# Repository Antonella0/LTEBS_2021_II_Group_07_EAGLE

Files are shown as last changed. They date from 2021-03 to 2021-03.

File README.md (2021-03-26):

# LTEBS_2021_II_Group_07_EAGLE
<h3> Group_07: Buquicchio Antonella, Di Liddo Mauro </h3>

<p> This folder contains all the files required for the first assignment. In particular you can find:
<u>
<li> The Library with the new components, TMUX1208 and TCA9546A
<li> The Schematic
<li> The Board
<li> The Design rules
<li> gitignore file </li>
</p>

<h3> Library: Group_07_Library.lbr </h3>
<p> In the library file are contained the two new components which are used in the schematic and in the board. For each device is present the symbol, the footprint and a
briefly description of the device itself. All the information are extracted from the datasheets of Texas Instruments:
<li> TMUX1208: the available package is QFN-16
<li> TCA9546A: the available package is TSSOP-16 </li>
</p>

<p> <b>Note_1</b>: In the TMUX1208, the association between pins of the symbol and pads of the footprint follows the QFN-16 one.</p>

<p> <b>Note_2</b>: The pads of the two components are realized with a rectangular shape without any roundness at the corners. </p>

</p>
<p> The graphical pins disposition of the TMUX1208 and TCA9546A is reorganized with respect to the one provided by the datasheets in order 
to allow an easier connection with the other components in the schematic.
</p>

</p>
<p> In addition to our library, we have used the SparkFun Library (https://github.com/sparkfun/SparkFun-Eagle-Libraries) and the CY8CKIT-059 Library 
(https://github.com/dado93/Cypress-Eagle). </p>

<h3>Schematic: Group_07.sch </h3>
<p> We have created the schematic starting from the given one and the list of components. It is arranged in one page.</p>

<h3>Board: Group_07.brd </h3>
<p> All the components are organized in the top layer. We have used traces width of 10 mils as requested with the exception of the TMUX1208 traces: indeed, the pads 
are very closed each others and, in order to respect the clearance requirements, we have decided to use 8 mils traces. 
</p>

<h3>Design Rules: Group_07.dru </h3>
<p>In order to decide the design rules, we have refered to the requirements of MDsrl (https://www.mdsrl.it/mddesignrules.html).
</p>

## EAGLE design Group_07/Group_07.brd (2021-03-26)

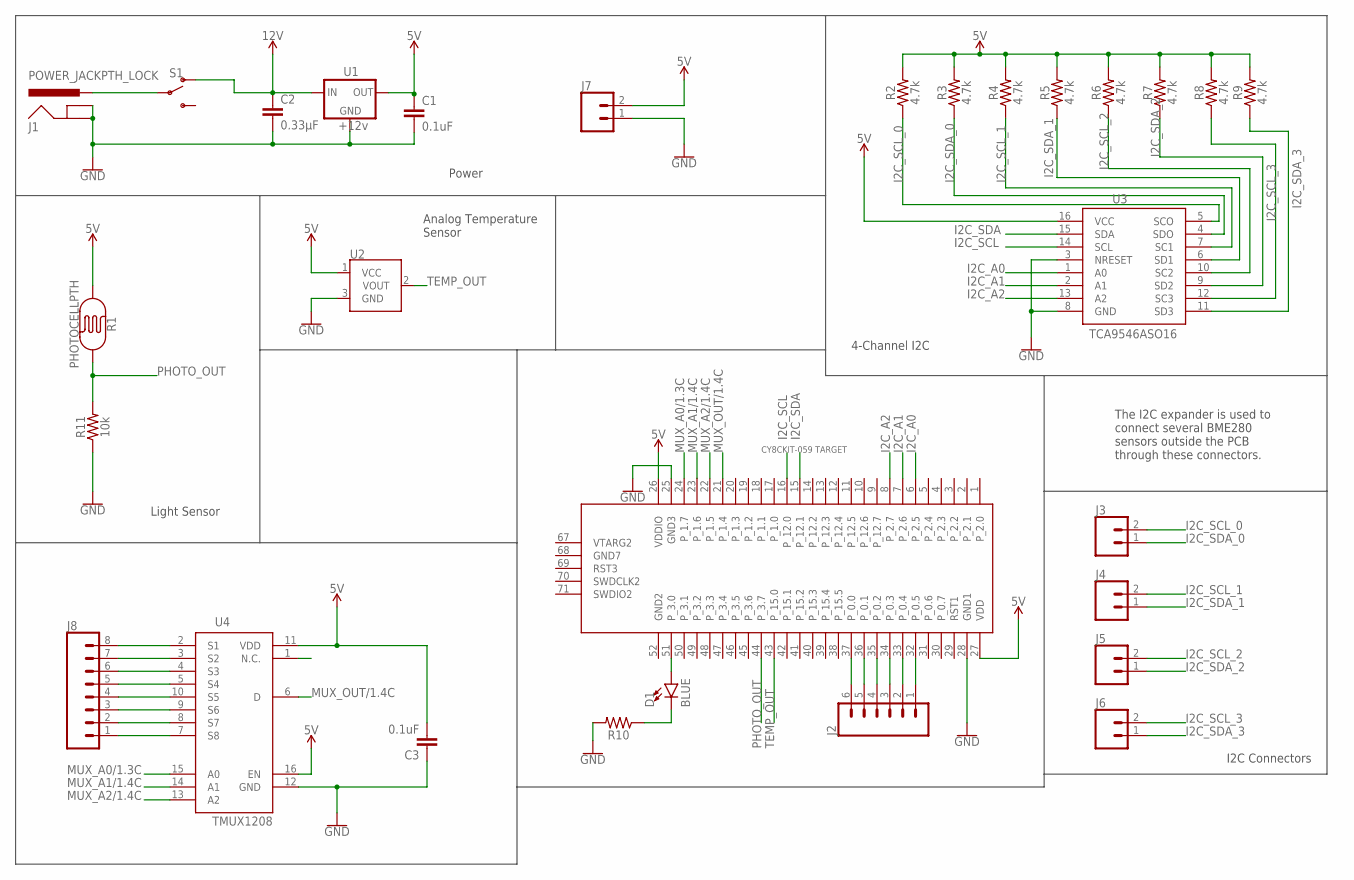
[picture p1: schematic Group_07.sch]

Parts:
C1, C3: 0.1uF; CAP-PTH-SMALL-KIT
C2: 0.33µF; 0805
D1: BLUE; LED-1206
J1: POWER_JACKPTH_LOCK; POWER_JACK_PTH_LOCK
J2: CONN_06LOCK; 1X06_LOCK
J3, J4, J5, J6, J7: CONN_02; 1X02
J8: CONN_08LOCK; 1X08_LOCK
R1: PHOTOCELLPTH; PHOTOCELL
R2, R3, R4, R5, R6, R7, R8, R9: 4.7k; 0603
R10: AXIAL-0.3
R11: 10k; 0603
S1: SWITCH-SPDT-PTH-11.6X4.0MM; SWITCH_SPDT_PTH_11.6X4.0MM
U1: +12v; TO-252
U2: TMP36GT9; TO-92
U3: TCA9546ASO16; TSSOP16
U4: TMUX1208; QFN16
U$1: CY8CKIT-059_TARGET

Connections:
5V: C1.1, C3.2, J7.2, R1.1, R2.2, R3.2, R4.2, R5.2, R6.2, R7.2, R8.2, R9.2, U1.2 (OUT), U2.1 (VCC), U3.16 (VCC), U4.11 (VDD), U$1.27 (VDD)
12V: C2.1, S1.1 (O), U1.1 (IN)
GND: C1.2, C2.2, C3.1, J1.GND, J1.GNDBREAK, J7.1, R10.P$2 (2), R11.1, U1.3 (GND), U2.3 (GND), U3.3 (NRESET), U3.8 (GND), U4.12 (GND), U$1.25 (GND3)
I2C_A0: U3.1 (A0), U$1.6 (P_2.5)
I2C_A1: U3.2 (A1), U$1.7 (P_2.6)
I2C_A2: U3.13 (A2), U$1.8 (P_2.7)
I2C_SCL: U3.14 (SCL), U$1.16 (P_12.0)
I2C_SCL_0: J3.2, R2.1, U3.5 (SCO)
I2C_SCL_1: J4.2, R4.1, U3.7 (SC1)
I2C_SCL_2: J5.2, R6.1, U3.10 (SC2)
I2C_SCL_3: J6.2, R8.1, U3.12 (SC3)
I2C_SDA: U3.15 (SDA), U$1.15 (P_12.1)
I2C_SDA_0: J3.1, R3.1, U3.4 (SDO)
I2C_SDA_1: J4.1, R5.1, U3.6 (SD1)
I2C_SDA_2: J5.1, R7.1, U3.9 (SD2)
I2C_SDA_3: J6.1, R9.1, U3.11 (SD3)
MUX_A0/1.3C: U4.15 (A0), U$1.24 (P_1.7)
MUX_A1/1.4C: U4.14 (A1), U$1.23 (P_1.6)
MUX_A2/1.4C: U4.13 (A2), U$1.22 (P_1.5)
MUX_OUT/1.4C: U4.6 (D), U$1.21 (P_1.4)
unnamed: J1.PWR, S1.2
unnamed: J8.8, U4.2 (S1)
unnamed: J2.6, U$1.37 (P_0.0)
unnamed: J2.5, U$1.36 (P_0.1)
unnamed: J2.4, U$1.35 (P_0.2)
unnamed: J2.3, U$1.34 (P_0.3)
unnamed: J2.2, U$1.33 (P_0.4)
unnamed: J2.1, U$1.32 (P_0.5)
unnamed: D1.A, U$1.51 (P_3.0)
unnamed: D1.C, R10.P$1 (1)
unnamed: J8.7, U4.3 (S2)
unnamed: J8.6, U4.4 (S3)
unnamed: J8.5, U4.5 (S4)
unnamed: J8.4, U4.10 (S5)
unnamed: J8.3, U4.9 (S6)
unnamed: J8.2, U4.8 (S7)
unnamed: J8.1, U4.7 (S8)
PHOTO_OUT: R1.2, R11.2, U$1.44 (P_3.7)
TEMP_OUT: U2.2 (VOUT), U$1.43 (P_15.0)

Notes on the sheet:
The I2C expander is used to connect several BME280 sensors outside the PCB through these connectors.
Power
Light Sensor
4-Channel I2C
I2C Connectors
Analog Temperature Sensor

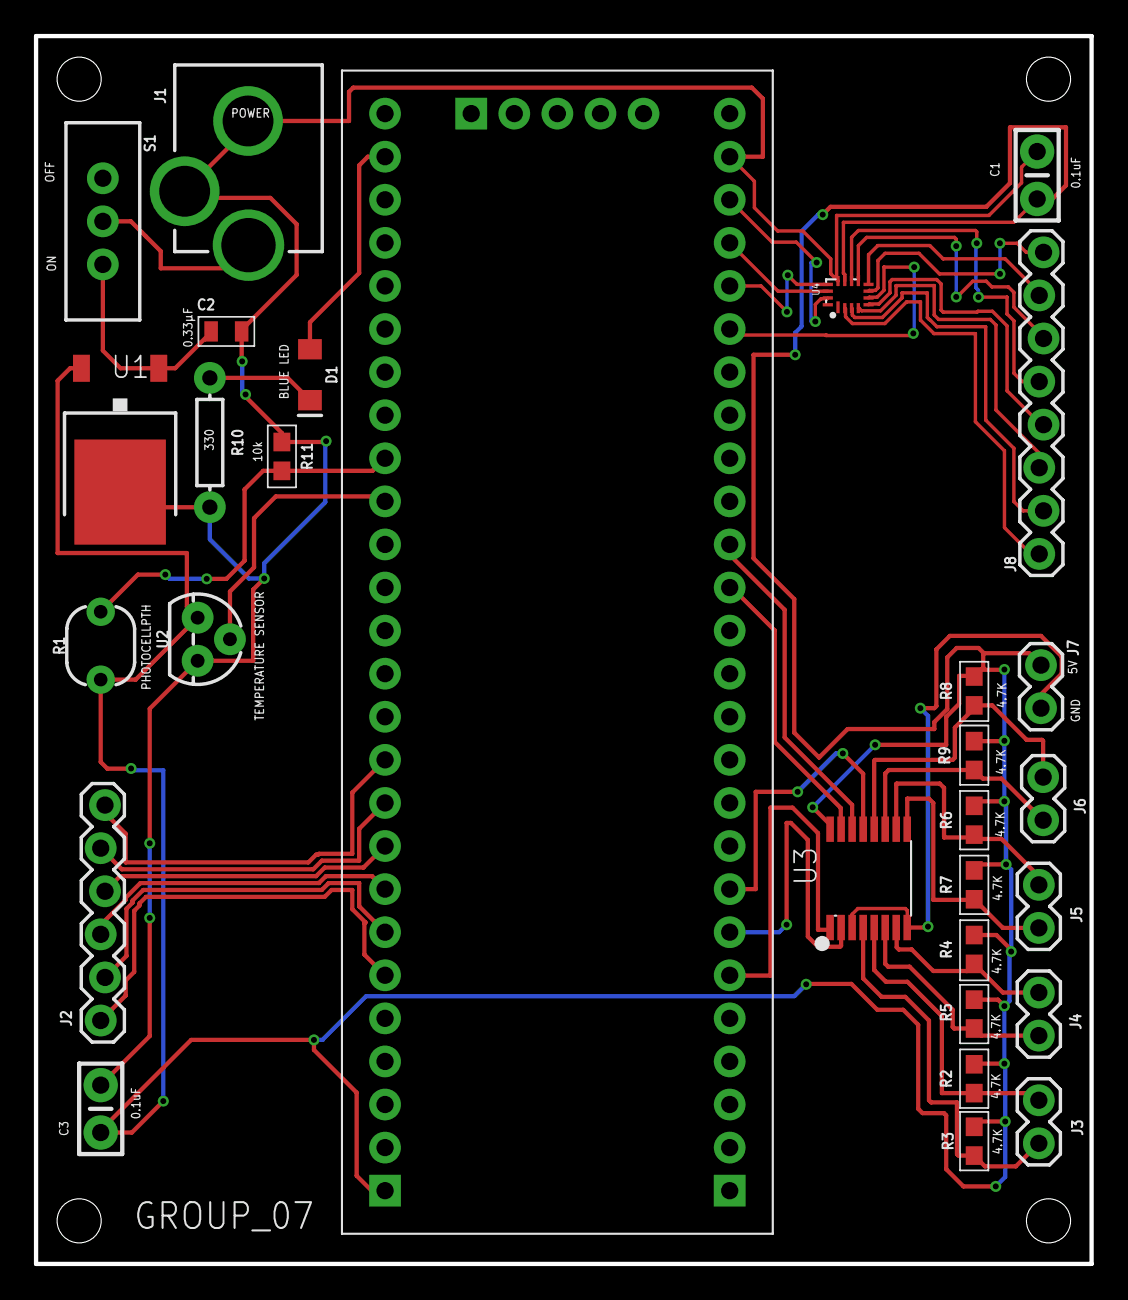
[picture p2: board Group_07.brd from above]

Board: 2 copper layers, 62.2 x 72.4 mm, 29 parts (0 on the bottom side), 39 nets.

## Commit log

2021-03-19 Changes in the disposition and details
    [Group_07.sch]
2021-03-19 Adding descriptions
    [Group_07.brd]
2021-03-19 Description library
    [Group_07.brd]
2021-03-20 Backup files
    [Group_07.brd]
2021-03-20 Revert "Backup files" This reverts commit c019932dfd2d236227c1f5919d51fad0ed4b2c4b. git commit -m "Revert changes"
    [Group_07.brd]
2021-03-20 FootPrint TMUX
    [Group_07.sch]
2021-03-20 Board start
    [Group_07.brd]
2021-03-21 Correction in the schematic
    [Group_07.sch]
2021-03-21 Disposition of the components and traces
    [Group_07.brd]
2021-03-22 modifica delle dimensioni vias
    [Group_07.brd]
2021-03-22 airwire da fixare per problemi di clearance
    [Group_07.brd]
2021-03-22 airwire fixed by replacing w/ width 8 instead of 10
    [Group_07.brd]
2021-03-22 all fixed w/ width8
    [Group_07.brd]
2021-03-23 Disposizione modificata
    [Group_07.brd]
2021-03-23 Connessioni TCA9546A
    [Group_07.brd]
2021-03-23 modifiche tmux
    [Group_07.brd]
2021-03-23 modifica lato sx board
    [Group_07.brd]
2021-03-23 modifica dimensioni traces
    [Group_07.brd]
2021-03-23 controllo ratsnest
    [Group_07.brd]
2021-03-23 aggiunta traces alimentazione e massa
    [Group_07.brd]
2021-03-23 risoluzione conflitti drc MD S.R.L.
    [Group_07.brd]
2021-03-24 Modifiche traces GND
    [Group_07.brd]
2021-03-24 Controllo DRC
    [Group_07.brd]
2021-03-24 aggiunta primi nomi componenti, holes e modifica descrizione DRC
    [Group_07.brd]
2021-03-25 riduzione dimensioni board e riposizionamento componenti con verifica dru
    [Group_07.brd]
2021-03-25 Modifica silkscreen, mask and DRC check
    [Group_07.brd, Group_07.sch]
2021-03-25 Holes e controllo traces
    [Group_07.brd]
2021-03-26 correzione holes
    [Group_07.brd]
2021-03-26 Creazione cartella
    [Group_07.brd, Group_07.sch]
2021-03-26 Final version
    [Group_07.brd, Group_07.sch]

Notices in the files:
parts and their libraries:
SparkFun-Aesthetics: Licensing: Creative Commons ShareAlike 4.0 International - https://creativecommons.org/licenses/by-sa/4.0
